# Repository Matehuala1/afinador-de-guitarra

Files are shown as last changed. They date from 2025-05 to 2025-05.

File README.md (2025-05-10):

# Afinador Digital para Guitarra con MSP430

Este proyecto implementa un **afinador digital para guitarra** usando el microcontrolador **MSP430**. Detecta la frecuencia de una señal de audio (como la de una cuerda vibrante), identifica la nota más cercana entre E2, A, D, G, B y E4, y muestra si la afinación es baja (bemol), precisa o alta (sostenido) mediante LEDs.

---

##  Funcionalidades

- Lectura de señal analógica mediante interrupciones del timer.
- Cálculo de frecuencia en tiempo real.
- Comparación con notas estándar para afinación de guitarra.
- Visualización de la nota detectada en un display.
- Indicadores LED para mostrar si la nota está afinada, baja o alta.

---

## Notas Soportadas

Las notas base utilizadas están en la afinación estándar de guitarra:

| Nota | Frecuencia (Hz) |
|---|---|
| E2 | 82 |
| A | 110 |
| D | 147 |
| G | 196 |
| B | 247 |
| E4 | 333 |

---

## Arquitectura del Código

- `TiposNotas`: Enumeración de notas musicales.
- `Notas`: Estructura que vincula una nota con su frecuencia.
- `tablaNotas[]`: Tabla de referencia para afinación.
- `detectarNota(f)`: Determina la nota más cercana a una frecuencia detectada.
- `indicarAfinacion(f, notaRef)`: Muestra si la cuerda está afinada, baja o alta.
- `mostrar_nota(nota)`: Visualiza la nota actual en el display.
- `TIMER0_A0_ISR`: ISR que mide la frecuencia a través de flancos de subida.

---

## Pines Utilizados (MSP430)

| Puerto | Función |
|---|---|
| P6.0 | Entrada de señal de audio |
| P1.0 | LED indicador de lectura |
| P2.X | Display de nota (7 segmentos) |
| P3.0–P3.4 | LEDs para afinación (bajo/alto/preciso) |
| P4.0 | Salida de prueba (osciloscopio)  |

---

## Cómo Funciona

1. El microcontrolador mide el período de la señal entrante mediante interrupciones del TimerA.
2. Calcula la frecuencia basada en el tiempo entre flancos.
3. Se compara la frecuencia con la tabla de notas estándar.
4. Se indica:
   - Nota detectada (en el display).
   - Estado de afinación (mediante LEDs).

---

## Requisitos

- Microcontrolador MSP430 (probado en LaunchPad MSP430G2553).
- Fuente de señal de audio (micrófono o captador piezoeléctrico).
- LEDs y display de 7 segmentos conectados a los pines indicados (PCB diseñada especificamente para esta aplicacion).

---

## Consideraciones

- El cálculo de desviación (bemol/sostenido) usa un ±6% respecto a la frecuencia de referencia.
- El código puede mejorarse usando tipos `float` para mayor precisión en comparación de afinación.
- Asegúrate de filtrar adecuadamente la señal para evitar falsas detecciones.

---

## Licencia

Este proyecto es de uso libre con fines educativos.

---

## Autor

Juan Gilberto Prado Matehuala
Jorge Eduardo Davila Garcia
Jonathan Brown Moreno
---

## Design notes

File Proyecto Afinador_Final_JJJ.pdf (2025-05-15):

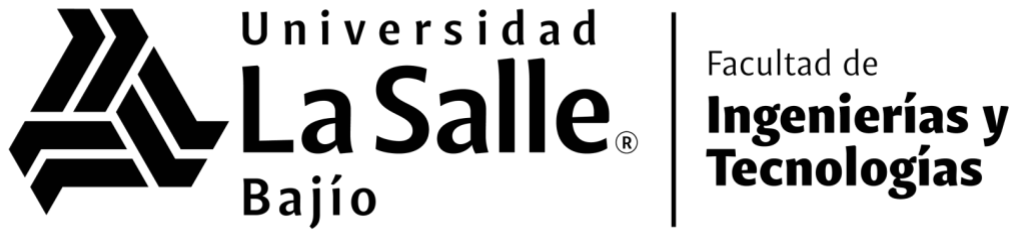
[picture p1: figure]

# Afinador de Guitarra

# Segundo Parcial

## Microcontroladores

## Alumnos:

## Juan Gilberto Prado Matehuala 6100019

## Jorge Eduardo Dávila García 6100016

## Jonathan Brown Moreno 6100006

11/05/25

## Objetivo

Implementar un sistema electrónico basado en el microcontrolador MSP430 para afinar guitarras mediante el análisis de frecuencias de las cuerdas, con indicación visual de la nota detectada y su estado de afinación.

## Objetivos específicos

1. Diseñar un circuito de acondicionamiento de señal para la guitarra eléctrica
2. Programar el MSP430 para medición precisa de frecuencia
3. Implementar un sistema de visualización con LEDs para notas y estado de afinación

## Introducción

El proyecto surge de la necesidad de crear un afinador de guitarras donde se ponga en práctica los temas vistos en clase. Nuestra solución utiliza el microcontrolador MSP430 para procesar la señal de audio, identificar la frecuencia fundamental y compararla con los valores estándar de las cuerdas de guitarra (E2, A, D, G, B, E4).

## Marco teórico

Teoría de funcionamiento

El dispositivo opera mediante:

1. Captura de señal: La guitarra se conecta a un jack de ¼"
2. Acondicionamiento: Circuito con amplificador operacional (LM358) para amplificar y cuadrar la señal
3. Procesamiento: El MSP430 mide el periodo entre flancos de subida
4. Cálculo: Conversión de periodo a frecuencia y comparación con valores de referencia
5. Visualización: LEDs indican la nota detectada y estado de afinación

Definiciones técnicas Frecuencias
de referencia:
- E2: 82.41 Hz
- A: 110.00 Hz
- D: 146.83 Hz
- G: 196.00 Hz
- B: 246.94 Hz
- E4: 329.63 Hz

Señal cuadrática amplificada y cuadrática

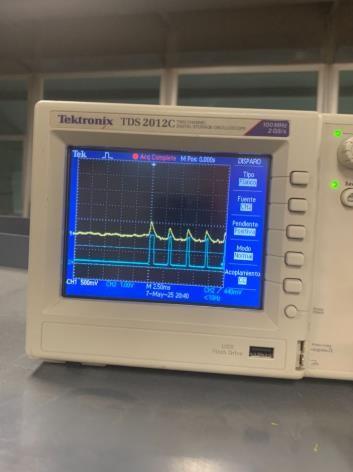
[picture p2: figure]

Señal de una cuerda de Guitarra con OPAMP cuadrático

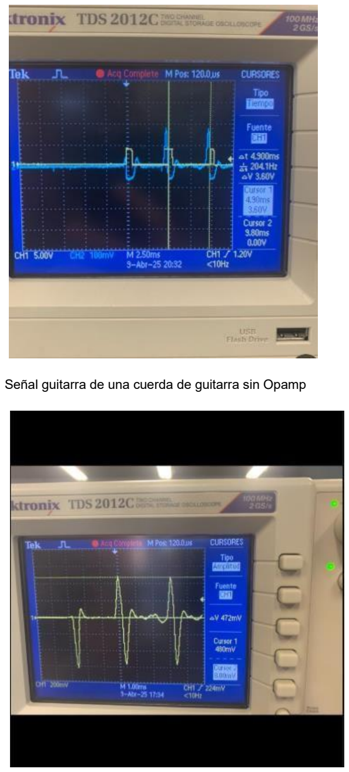
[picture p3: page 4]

Señal guitarra de una cuerda de guitarra sin Opamp

Materiales utilizados
1. Microcontrolador MSP430F5529
2. Amplificador operacional LM358
3. Resistencias, Capacitores, Potenciometros
4. LEDs para visualización (5 unidades)
5. PCB personalizado
6. Cable Jack guitarra
7. Guitarra

## Desarrollo

Proceso de implementación 1.
Fase inicial (Semanas 1-2):
- Investigación de señales de guitarra y circuitos comerciales
- Selección de componentes electrónicos
- Diseño conceptual del código
2. Prototipado (Semana 3):
- Pruebas con osciloscopio de señales de guitarra
- Diseño de placa PCB enviado a fabricación
- Desarrollo de código base para medición de frecuencia
3. Implementación final (Semanas 4-5):
- Recepción y soldadura de PCB
- Implementación de circuito amplificador/cuadrático
- Pruebas del código

## Diagramas

1. Esquemático electrónico completo

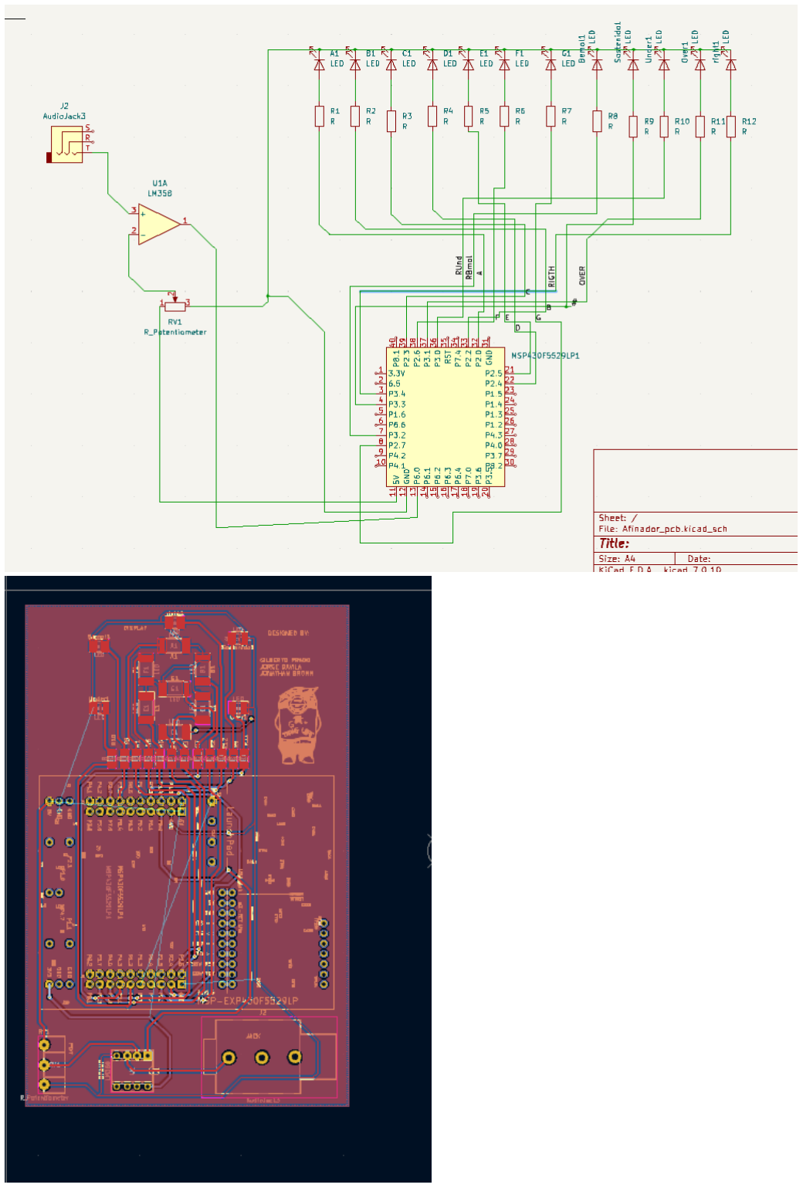
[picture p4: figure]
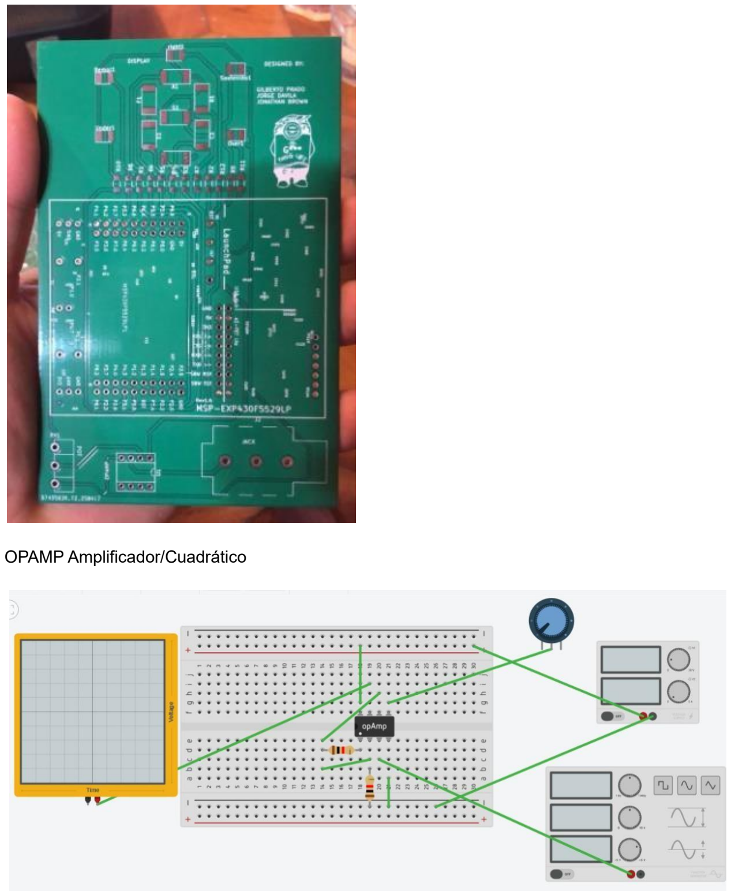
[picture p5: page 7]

OPAMP Amplificador/Cuadrático

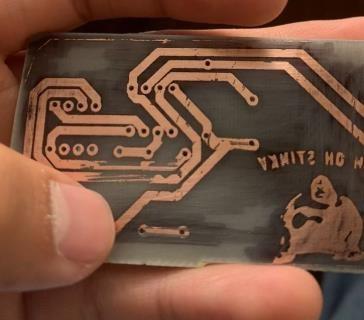
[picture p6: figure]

2. Fotos del prototipo final

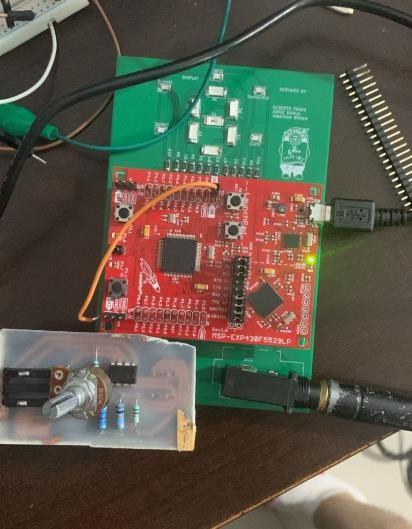
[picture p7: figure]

## Resultados

Logros obtenidos
- Circuito amplificador/condicionador funcional que transforma la señal senoidal en cuadrada
- Se logra visualizar con un osciloscopio la señal de la guitarra en la MSP
- Detección de algunas cuerdas como E2, A, B y E4
- Visualización en LEDs

Desafíos técnicos
1. Amplificación de señal:

Para garantizar un procesamiento adecuado, se implementó un circuito amplificador que mejoró significativamente la calidad de la señal de entrada. Este sistema, combinado con un amplificador operacional configurado como comparador, transformó la señal de la guitarra en una onda cuadrada precisa para obtener pulsos, facilitando su análisis por el microcontrolador.

2.Precisión en la afinación:

Durante las pruebas finales, el sistema demostró capacidad para identificar correctamente las notas E2, A, B y E4. Sin embargo, se presentaron inconsistencias en la detección del estado de afinación exacto. En una versión del código se logró afinar perfectamente la cuerda A, pero esto afectó la detección de otras notas. Se optó por mantener la versión anterior con menor precisión en la afinación, pero se obtenía un funcionamiento más estable sin tanta variación para todas las cuerdas.

3. Problemas de hardware:
- Ruido eléctrico en las primeras pruebas
- Sensibilidad a variaciones de amplitud de la señal

Posibles mejoras
1. Implementar filtrado digital adicional en el código
2. Añadir calibración sin necesidad de un sesgo (potenciometro)
3. Mejorar el circuito de acondicionamiento para mayor inmunidad al ruido
4. Implementar circuito para alimentar a luz y conexión a otras pedaleras para un uso más práctico.

Fotos del resultado:

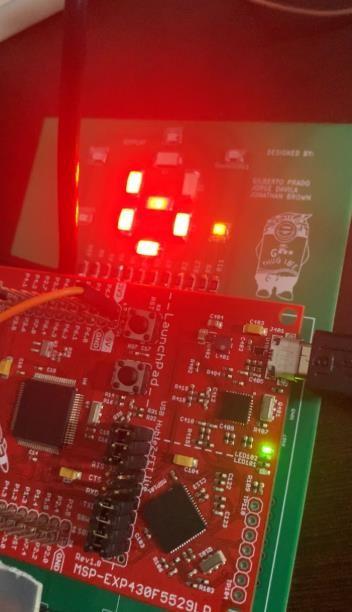
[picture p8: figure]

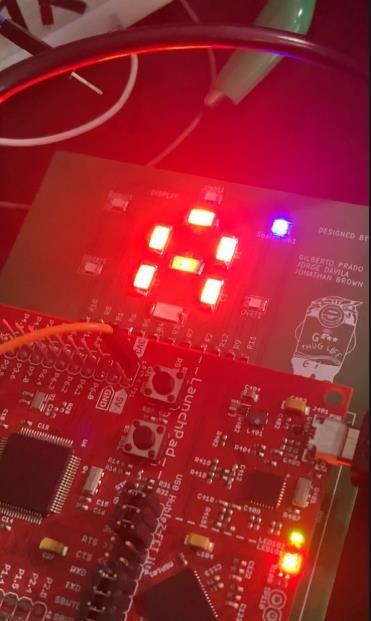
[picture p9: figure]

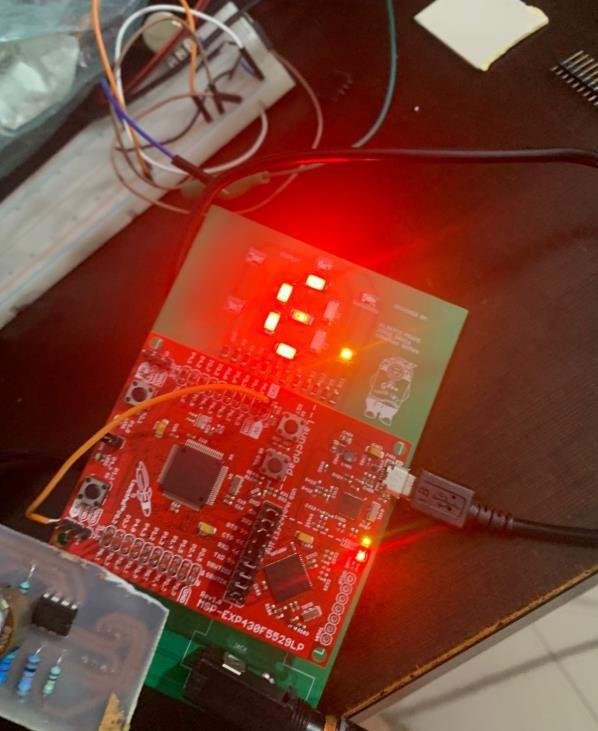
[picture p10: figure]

## Conclusión

Aprendizajes individuales
- Juan Gilberto: Se logró aplicar temas de diferentes materias para el circuito electrónico, además se puso la práctica el diseño de placa y programación.

- Jonathan: Desarrollé habilidades en programación de microcontroladores.
- Jorge Eduardo: Se comprendió mejor el uso de los OPAMPS, así como se busco de diferentes maneras lograr comparar la señal que se recibía y que la MSP la interpretara como una Nota definida.

Conclusiones generales

El proyecto logró implementar varias alternativas y recursos de clases para crear un afinador de guitarra de bajo costo basado en el MSP430, aún que haya formas diferentes para realizarlo, se logró una funcionalidad muy básica, se identificaron áreas de mejora para versiones futuras, particularmente en la precisión de la detección de afinación y la tolerancia del sistema ante variaciones de señal que recibe. Por último, se logró identificar un error clave en la programación, el timer hacia cuentas muy largas por lo que tardaba demasiado y era muy lento para poder identificar las frecuencias. El modificar la configuración del timer para poder leer más ciclos logró que sea aún más sencillo programar y nos acercó a un resultado más acercado a lo esperado.

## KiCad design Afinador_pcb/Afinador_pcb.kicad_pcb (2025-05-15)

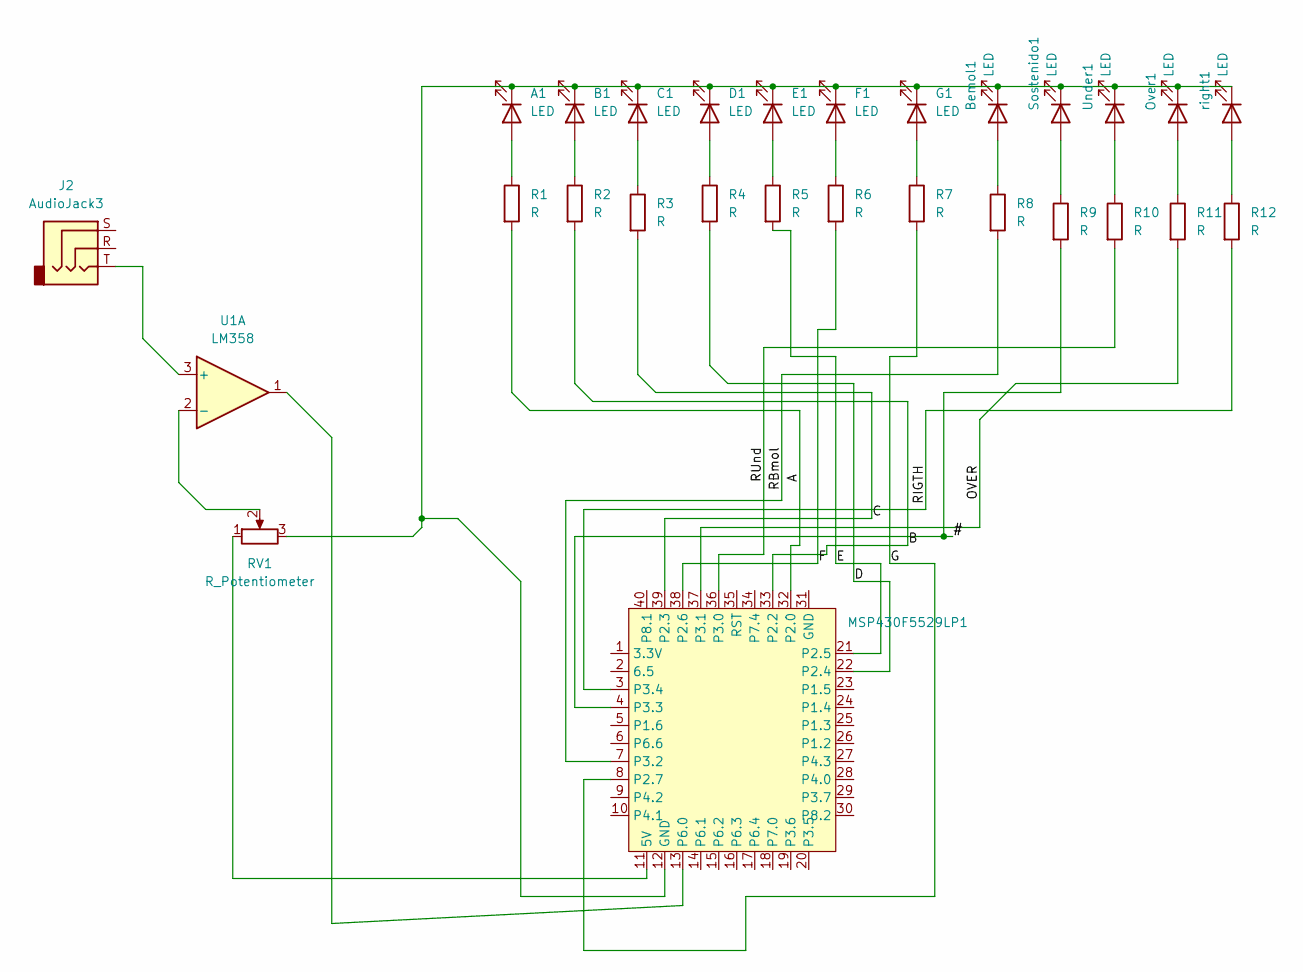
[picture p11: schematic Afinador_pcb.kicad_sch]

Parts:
A1: LED; LED_2512_6332Metric_Pad1.52x3.35mm_HandSolder
B1: LED; LED_2512_6332Metric_Pad1.52x3.35mm_HandSolder
Bemol1: LED; LED_1210_3225Metric_Pad1.42x2.65mm_HandSolder
C1: LED; LED_2512_6332Metric_Pad1.52x3.35mm_HandSolder
D1: LED; LED_2512_6332Metric_Pad1.52x3.35mm_HandSolder
E1: LED; LED_2512_6332Metric_Pad1.52x3.35mm_HandSolder
F1: LED; LED_2512_6332Metric_Pad1.52x3.35mm_HandSolder
G1: LED; LED_2512_6332Metric_Pad1.52x3.35mm_HandSolder
J2: AudioJack3; Jack_6.35mm_Neutrik_NMJ6HFD3_Horizontal
MSP430F5529LP1: MSP430F5529LP
Over1: LED; LED_1210_3225Metric_Pad1.42x2.65mm_HandSolder
R1, R2, R3, R4, R5, R6, R7, R8, R9, R10, R11, R12: R; R_1206_3216Metric_Pad1.30x1.75mm_HandSolder
RV1: R_Potentiometer; Potentiometer_ACP_CA14-H2,5_Horizontal
Sostenido1: LED; LED_1210_3225Metric_Pad1.42x2.65mm_HandSolder
U1: LM358; DIP-8_W7.62mm_Socket
Under1: LED; LED_1210_3225Metric_Pad1.42x2.65mm_HandSolder
right1: LED; LED_1210_3225Metric_Pad1.42x2.65mm_HandSolder

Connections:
/#: MSP430F5529LP1.4 (P3.3), R9.2
/A: MSP430F5529LP1.32 (P2.0), R1.2
/B: MSP430F5529LP1.33 (P2.2), R2.2
/C: MSP430F5529LP1.39 (P2.3), R3.2
/D: MSP430F5529LP1.22 (P2.4), R4.2
/E: MSP430F5529LP1.21 (P2.5), R5.2
/F: MSP430F5529LP1.38 (P2.6), R6.2
/G: MSP430F5529LP1.8 (P2.7), R7.2
/OVER: MSP430F5529LP1.37 (P3.1), R11.2
/RBmol: MSP430F5529LP1.7 (P3.2), R8.2
/RIGTH: MSP430F5529LP1.3 (P3.4), R12.2
/RUnd: MSP430F5529LP1.36 (P3.0), R10.2
unnamed: A1.2 (A), R1.1
unnamed: A1.1 (K), B1.1 (K), Bemol1.1 (K), C1.1 (K), D1.1 (K), E1.1 (K), F1.1 (K), G1.1 (K), MSP430F5529LP1.12 (GND), Over1.1 (K), RV1.3, Sostenido1.1 (K), Under1.1 (K), right1.1 (K)
unnamed: B1.2 (A), R2.1
unnamed: Bemol1.2 (A), R8.1
unnamed: C1.2 (A), R3.1
unnamed: D1.2 (A), R4.1
unnamed: E1.2 (A), R5.1
unnamed: F1.2 (A), R6.1
unnamed: G1.2 (A), R7.1
unnamed: MSP430F5529LP1.11 (5V), RV1.1
unnamed: MSP430F5529LP1.13 (P6.0), U1.1
unnamed: Over1.2 (A), R11.1
unnamed: R9.1, Sostenido1.2 (A)
unnamed: J2.T, U1.3 (+)
unnamed: RV1.2, U1.2 (-)
unnamed: R10.1, Under1.2 (A)
unnamed: R12.1, right1.2 (A)

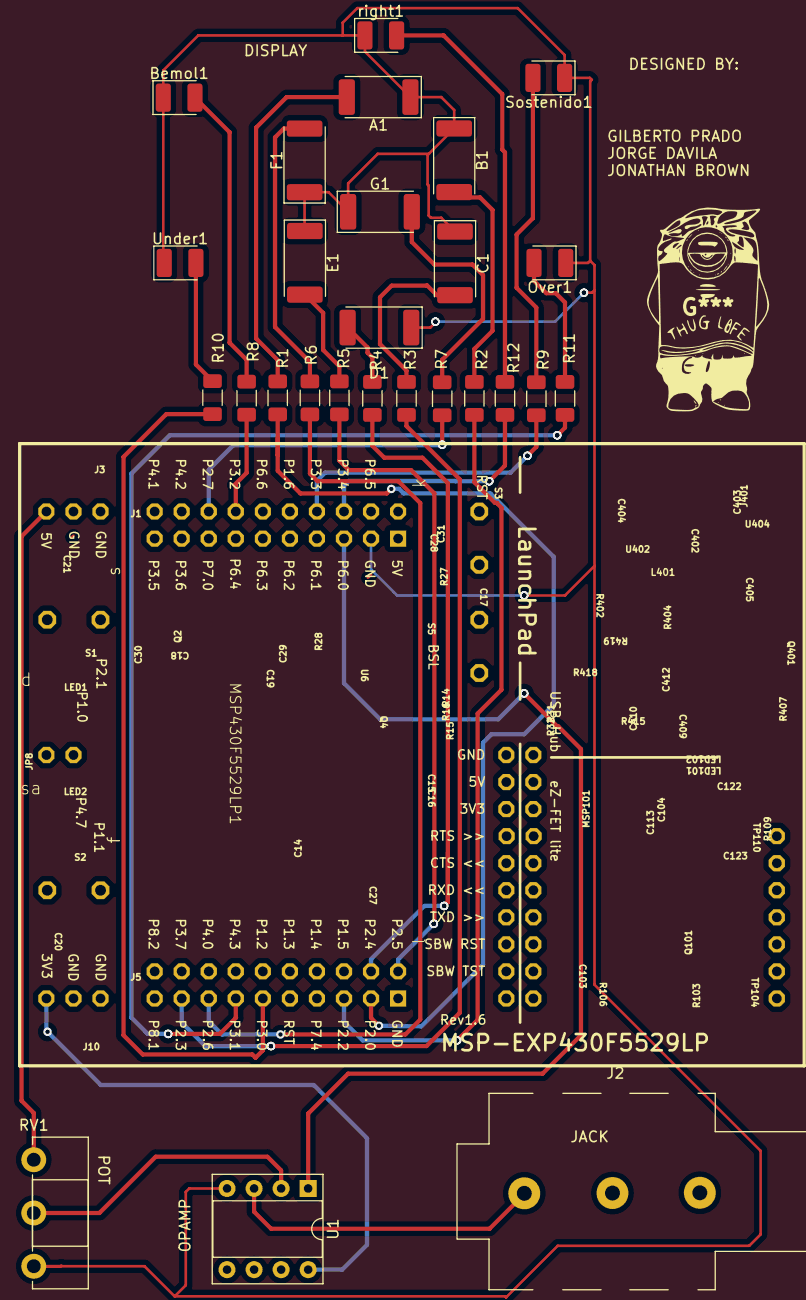
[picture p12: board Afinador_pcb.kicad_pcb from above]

Board: 2 copper layers, 28 parts (0 on the bottom side), 29 nets.

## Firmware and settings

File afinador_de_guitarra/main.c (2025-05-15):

/**
 * @file main.c
 * @brief Afinador de guitarra para MSP430.
 *
 * Este programa implementa un afinador de guitarra utilizando el microcontrolador MSP430.
 * Mide la frecuencia de la señal de entrada (cuerda de guitarra), detecta la nota musical más cercana,
 * la muestra en un display y enciende LEDs indicadores para mostrar si la afinación está baja, precisa o alta.
 *
 * Funcionalidades principales:
 * - Configuración de pines y temporizador.
 * - Medición de frecuencia de la señal de entrada.
 * - Detección de la nota musical más cercana.
 * - Indicación visual de la nota y del estado de afinación mediante LEDs.
 *
 * Notas soportadas: E2 (82 Hz), A (110 Hz), D (147 Hz), G (196 Hz), B (247 Hz), E4 (333 Hz).
 *
 * @author Juan Gilberto Prado Matehuala
 * @author Jonathan Brown Moreno
 * @author Jorge Eduardo Davila Garcia
 * @date 10/05/2025
 */

#include <msp430.h> 

// Enumeracion para representar las notas musicales que se afinan
typedef enum {
    E2, // 82 Hz
    A, // 110 Hz
    D, // 147 Hz
    G, // 196 Hz
    B, // 247 Hz
    E4  // 333Hz
} TiposNotas;

// Estructura que asocia una nota con su frecuencia
typedef struct {
    TiposNotas nota;
    unsigned int frequencia;
} Notas;

// Tabla de notas de referencia
Notas tablaNotas[] = {
    {E2, 82},
    {A, 110},
    {D, 147},
    {G, 196},
    {B, 247},
    {E4, 333},
};

// Declaración de funciones
void confg_pines(void);     // Configura los pines de lectura
void confg_relog(void);     // Configura el temporizador

void mostrar_nota(TiposNotas nota);
TiposNotas detectarNota(unsigned int f);
void indicarAfinacion(unsigned int freqEntrada, Notas notaRef);

// Variables globales
float factor = 0.0004;          // Factor de conversión de cuentas a segundos (100 us)
unsigned int frecuencia = 0;      // Resultado de la frecuencia
unsigned char estado_anterior = 1; // Estado anterior del pin
unsigned int cuenta = 0;          // Contador de ciclos del timer
float periodo = 0;                // Periodo medido
unsigned char nueva_medida = 0;
volatile unsigned int flancos = 0;
volatile unsigned char ventana_lista = 0;
volatile unsigned int ventana_contador = 0; // Agrega esta variable global
volatile unsigned int debounce_counter = 0; // Global

int main(void)
{
    WDTCTL = WDTPW | WDTHOLD;     // Stop watchdog timer

    confg_pines();
    confg_relog();

    __enable_interrupt();         // Habilitar interrupciones globales

    while(1){
        if (ventana_lista) {
            ventana_lista = 0;
            frecuencia = flancos * 10; // Si la ventana es de 100 ms, multiplica por 10 para Hz
            flancos = 0;

            TiposNotas nota = detectarNota(frecuencia);
            mostrar_nota(nota);
            indicarAfinacion(frecuencia, tablaNotas[nota]);
        }
    }

    return 0;
}

void confg_pines(void){

    //pin de lectura
    P6DIR = 0x00;     // Pin P6.0 como entrada
    P6REN |= 0x01;    // Habilitar resistencia en P6.0
    P6OUT |= 0x01;    // Configurar como pull-up

    //leds display
    P2DIR = 0xFD;     // LEDs del display 2.0, 2.2 2.3 2.4 2.5 2.6 2.7   FR = 1111 1101
    P2OUT = ~0xFD;     // LEDs apagados inicialmente

    //leds indicadores
    P3DIR = 0x1F;     // LEDs indicadores   3.0 3.1 3.2 3.3 3.4
    P3OUT = ~0x1F;     // LED apagado inicialmente

}

void confg_relog(void){
    TA0CCTL0 = CCIE;
    TA0CCR0 = 60; // 100 ciclos de reloj (100 us si SMCLK = 1 MHz)
    TA0CTL = TASSEL_2 | MC_1 | ID_0 | TACLR;
}

void mostrar_nota(TiposNotas nota) {
    const unsigned char segmentos[] = {
        0xF1, // E
        0xED, // A
        0xF8, // D
        0x79, // G
        0xBC, // B
        0xF1, // E
    };
    P2OUT = (P2OUT & ~0xFD) | segmentos[nota]; // Aplicar solo a segmentos
}

// Devuelve la nota mas cercana a una frecuencia dada
TiposNotas detectarNota(unsigned int f) {
    // Calcula la diferencia absoluta entre la frecuencia medida y la frecuencia de referencia de cada nota
    unsigned int dif0 = (f > tablaNotas[0].frequencia) ? f - tablaNotas[0].frequencia : tablaNotas[0].frequencia - f; // Diferencia con E2 (82 Hz)
    unsigned int dif1 = (f > tablaNotas[1].frequencia) ? f - tablaNotas[1].frequencia : tablaNotas[1].frequencia - f; // Diferencia con A2 (110 Hz)
    unsigned int dif2 = (f > tablaNotas[2].frequencia) ? f - tablaNotas[2].frequencia : tablaNotas[2].frequencia - f; // Diferencia con D3 (147 Hz)
    unsigned int dif3 = (f > tablaNotas[3].frequencia) ? f - tablaNotas[3].frequencia : tablaNotas[3].frequencia - f; // Diferencia con G3 (196 Hz)
    unsigned int dif4 = (f > tablaNotas[4].frequencia) ? f - tablaNotas[4].frequencia : tablaNotas[4].frequencia - f; // Diferencia con B3 (247 Hz)
    unsigned int dif5 = (f > tablaNotas[5].frequencia) ? f - tablaNotas[5].frequencia : tablaNotas[5].frequencia - f; // Diferencia con E4 (333 Hz)

    // Inicializa la variable "menor" con la primera diferencia para comparar despues
    unsigned int menor = dif0;

    TiposNotas mejor = E2;

    if (dif1 < menor) { menor = dif1; mejor = A; }
    if (dif2 < menor) { menor = dif2; mejor = D; }
    if (dif3 < menor) { menor = dif3; mejor = G; }
    if (dif4 < menor) { menor = dif4; mejor = B; }
    if (dif5 < menor) { menor = dif5; mejor = E4; }

    return mejor;
}

void indicarAfinacion(unsigned int freqEntrada, Notas notaRef) {
    P3OUT &= ~0x1F;

    float margen = notaRef.frequencia * 0.06f; // 6% de la frecuencia de referencia
    float bajo = notaRef.frequencia - margen;
    float alto = notaRef.frequencia + margen;

    if (freqEntrada < bajo)
        P3OUT |= 0x01; // bemol (muy baja)
    else if (freqEntrada >= bajo && freqEntrada < notaRef.frequencia)
        P3OUT |= 0x04; // leve baja (bemol)
    else if (freqEntrada >= notaRef.frequencia && freqEntrada <= alto)
        P3OUT |= 0x08; // sostenido
    else if (freqEntrada > alto)
        P3OUT |= 0x02; // muy alta
    else
        P3OUT |= 0x10; // afinado (exacto)
}

#pragma vector=TIMER0_A0_VECTOR
__interrupt void TIMER0_A0_ISR(void){
    unsigned char estado_actual = (P6IN & 0x01);

    // Incrementa el contador de debounce
    if (debounce_counter < 65535) debounce_counter++;

    // Detectar flanco de subida con debounce
    if ((estado_actual == 1) && (estado_anterior == 0)) {
        if (debounce_counter > 10) { // 10*100us = 1ms mínimo entre flancos
            flancos++;
            debounce_counter = 0;
        }
    }
    estado_anterior = estado_actual;

    // Ventana de 100 ms (1000 interrupciones de 100 us)
    ventana_contador++;
    if (ventana_contador >= 1000) {
        ventana_lista = 1;
        ventana_contador = 0;
    }
}

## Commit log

2025-05-10 correccion de muestra en el display
2025-05-15 Final Result
    [Afinador_pcb-B_Cu.gbr, Afinador_pcb-B_Mask.gbr, Afinador_pcb-B_Paste.gbr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]
